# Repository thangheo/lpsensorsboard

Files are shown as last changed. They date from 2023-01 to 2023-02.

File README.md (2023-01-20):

# low power sensorsboard
một mạng cảm biến tự làm chạy bằng pin với nhiều loại cảm biến cho nhà thông minh.
PCB và sơ đồ được thiết kế bằng Kicad 6.0.
một phần của cấu hình firmare được tạo bởi STM CubeMX.

Ở phiên bản hiện tại, các cảm biến được hỗ trợ là Cường độ ánh sáng sử dụng điện trở quang (ánh sáng rất yếu, <5 Lux),
Cảm biến CO2/độ ẩm/nhiệt độ từ sensirion SCD41(từ Seeedstudio
với đầu nối Grove), cảm biến âm thanh (Micrô), cảm biến CO/NH3, cảm biến AM2320 cho độ ẩm và nhiệt độ.
Tôi chưa thử nghiệm trên phần cứng thực vì tôi chỉ thiết kế PCB và lập trình Firmware vài tuần trước.
Vi điều khiển là STM32L051 với lõi Cortex M0+, ở chế độ STANDBY, mức tiêu thụ điện năng có thể giảm xuống mức thấp nhất là vài micro amp.
Theo tính toán của tôi, thiết bị có thể chạy tới 7-8 tháng với thời gian đo 2 phút với
 Pin Lithium 18658 (1000mAh). Nếu không có cảm biến CO/NH3, nó có thể chạy tới nhiều năm mà không cần sạc lại
  pin vì cảm biến này tiêu thụ một nửa năng lượng (35mA trong tổng số 70mA).
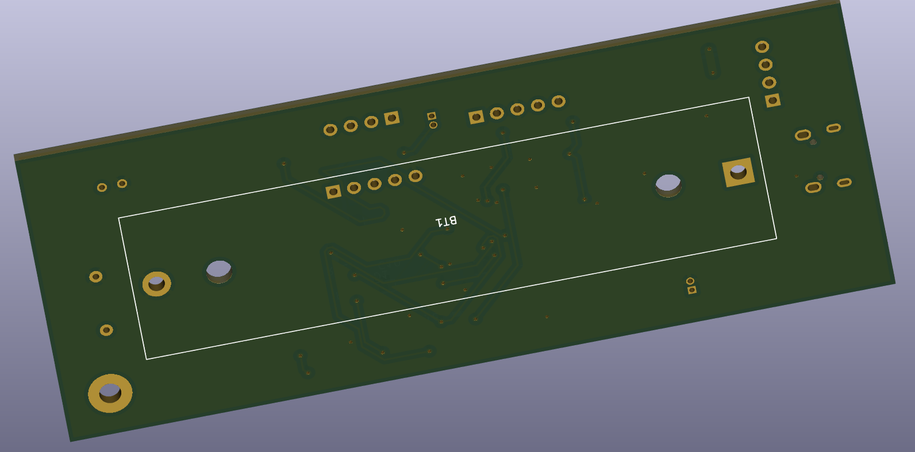
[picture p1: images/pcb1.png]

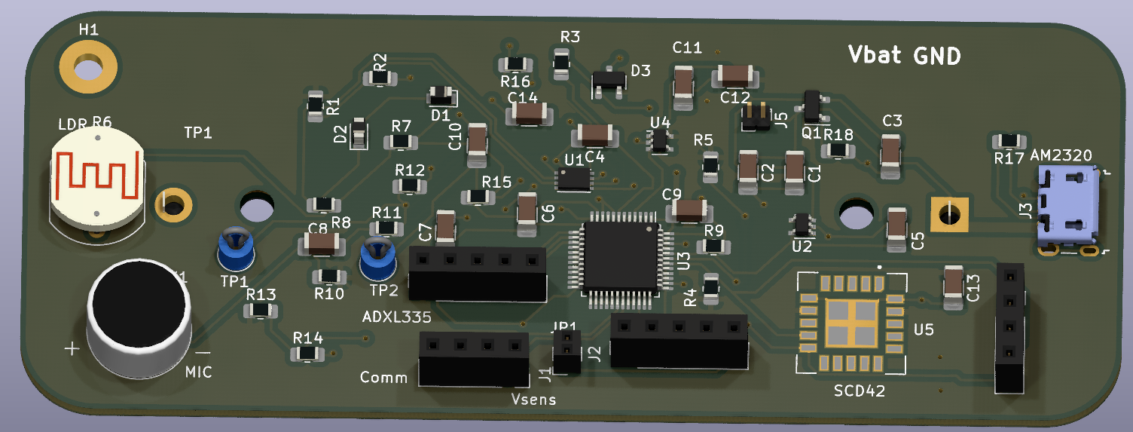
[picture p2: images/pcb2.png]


1. Cấu trúc dữ liệu gửi đi (bổ sung sau)

typedef struct {
  unsigned int temperature;
  unsigned int humidity;
  unsigned int AM2320_temperature;
  unsigned int AM2320_humidity;
  unsigned int audio;
  unsigned int light;
  unsigned int CO2;
  unsigned int NH3;
}

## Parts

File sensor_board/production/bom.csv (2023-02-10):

Designator | Footprint | Quantity | Value | LCSC Part #
BT1 | BatteryHolder_MPD_BH-18650-PC2 | 1 | Battery_Cell
C1 | 1206 | 1 | 1u
C10 | 1206 | 1 | 1u
C11 | 1206 | 1 | 1u
C12 | 1206 | 1 | 1u
C13 | 1206 | 1 | 1u
C14 | 1206 | 1 | 1n
C2 | 1206 | 1 | 4.7u
C3 | 1206 | 1 | 1u
C4 | 1206 | 1 | 0.1u
C5 | 1206 | 1 | 1u
C6 | 1206 | 1 | 0.1u
C7 | 1206 | 1 | 0.1u
C8 | 1206 | 1 | 1u
C9 | 1206 | 1 | 1u
D1, D2 | D_SOD-110 | 2 | 1N4728
D3 | SOT-23 | 1 | D_Zener_Dual_CommonAnode_KKA
H1 | MountingHole_2.7mm_M2.5_Pad | 1 | MountingHole
J1 | PinSocket_1x04_P2.54mm_Vertical | 1 | zigbee connector
J2 | PinSocket_1x05_P2.54mm_Vertical | 1 | SWD
J3 | USB_Micro-B_Wuerth_629105150521 | 1 | USB_B_Micro
J4 | PinSocket_1x04_P2.54mm_Vertical | 1 | AM2320
J5 | PinHeader_1x02_P1.27mm_Vertical | 1 | Lithium_battery_conn
J6 | PinSocket_1x05_P2.54mm_Vertical | 1 | ACC
J7 | TerminalBlock_bornier-2_P5.08mm | 1 | DBG_PWR
JP1 | PinSocket_1x02_P1.27mm_Vertical | 1 | 3.3v Jumper
MK1 | MIC_AOM-6738P-R | 1 | AOM-6738P-R
Q1 | SOT-23 | 1 | DMP3098LQ
R1 | 0805 | 1 | 100k
R10 | 0805 | 1 | 1k
R11 | 0805 | 1 | 1k
R12 | 0805 | 1 | 1k
R13 | 0805 | 1 | 22k
R14 | 0805 | 1 | 22k
R15 | 0805 | 1 | 20k
R16 | 0805 | 1 | 4.7k
R17 | 0805 | 1 | 200
R18 | 0805 | 1 | 10k
R19 | 0805 | 1 | 470
R2 | 0805 | 1 | 10k
R20 | 0805 | 1 | 470
R3 | 0805 | 1 | 10k
R4 | 0805 | 1 | 10k
R5 | 0805 | 1 | 10k
R6 | R_LDR_10x8.5mm_P7.6mm_Vertical | 1 | LDR03
R7 | 0805 | 1 | 100k
R8 | 0805 | 1 | 1k
R9 | 0805 | 1 | 10k
TP1, TP2 | TestPoint_Loop_D2.60mm_Drill1.6mm_Beaded | 2 | TestPoint
U1 | DFN-8-1EP_3x2mm_P0.5mm_EP1.75x1.45mm | 1 | MCP6002-xMC
U2, U4 | SOT-353_SC-70-5 | 2 | MIC5365-3.3YC5
U3 | LQFP-48_7x7mm_P0.5mm | 1 | STM32L051C8Tx
U5 | XDCR_SCD41-D-R2 | 1 | SDC42

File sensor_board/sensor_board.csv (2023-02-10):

Source: | /home/tng/work/nhayen/electronic/sensor/sensor_board/sensor_board.kicad_sch
Date: | Thứ ba, 07 Tháng 2 Năm 2023 21:50:40 +07
Tool: | Eeschema 6.0.11-2627ca5db0~126~ubuntu22.04.1
Generator: | /usr/share/kicad/plugins/bom_csv_grouped_by_value.py
Component Count: | 59
Individual Components:
Item | Qty | Reference(s) | Value | LibPart | Footprint | Datasheet | MANUFACTURER | MAXIMUM_PACKAGE_HEIGHT | PARTREV | SNAPEDA_PN | STANDARD
 |  | BT1 | Battery_Cell | Device:Battery_Cell | Battery:BatteryHolder_MPD_BH-18650-PC2 | ~
 |  | C1 | 1u | Device:C | Capacitor_SMD:C_1206_3216Metric_Pad1.33x1.80mm_HandSolder | ~
 |  | C2 | 4.7u | Device:C | Capacitor_SMD:C_1206_3216Metric_Pad1.33x1.80mm_HandSolder | ~
 |  | C3 | 1u | Device:C | Capacitor_SMD:C_1206_3216Metric_Pad1.33x1.80mm_HandSolder | ~
 |  | C4 | 0.1u | Device:C | Capacitor_SMD:C_1206_3216Metric_Pad1.33x1.80mm_HandSolder | ~
 |  | C5 | 1u | Device:C | Capacitor_SMD:C_1206_3216Metric_Pad1.33x1.80mm_HandSolder | ~
 |  | C6 | 0.1u | Device:C | Capacitor_SMD:C_1206_3216Metric_Pad1.33x1.80mm_HandSolder | ~
 |  | C7 | 0.1u | Device:C | Capacitor_SMD:C_1206_3216Metric_Pad1.33x1.80mm_HandSolder | ~
 |  | C8 | 1u | Device:C | Capacitor_SMD:C_1206_3216Metric_Pad1.33x1.80mm_HandSolder | ~
 |  | C9 | 1u | Device:C | Capacitor_SMD:C_1206_3216Metric_Pad1.33x1.80mm_HandSolder | ~
 |  | C10 | 1u | Device:C | Capacitor_SMD:C_1206_3216Metric_Pad1.33x1.80mm_HandSolder | ~
 |  | C11 | 1u | Device:C | Capacitor_SMD:C_1206_3216Metric_Pad1.33x1.80mm_HandSolder | ~
 |  | C12 | 1u | Device:C | Capacitor_SMD:C_1206_3216Metric_Pad1.33x1.80mm_HandSolder | ~
 |  | C13 | 1u | Device:C | Capacitor_SMD:C_1206_3216Metric_Pad1.33x1.80mm_HandSolder | ~
 |  | C14 | 1n | Device:C | Capacitor_SMD:C_1206_3216Metric_Pad1.33x1.80mm_HandSolder | ~
 |  | C15 | 0.1u | Device:C | Capacitor_SMD:C_1206_3216Metric_Pad1.33x1.80mm_HandSolder | ~
 |  | C16 | 0.1u | Device:C | Capacitor_SMD:C_1206_3216Metric_Pad1.33x1.80mm_HandSolder | ~
 |  | C17 | 0.1u | Device:C | Capacitor_SMD:C_1206_3216Metric_Pad1.33x1.80mm_HandSolder | ~
 |  | D1 | 1N4728 | Device:D_Zener | Diode_SMD:D_SOD-110 | ~
 |  | D2 | 1N4728 | Device:D_Zener | Diode_SMD:D_SOD-110 | ~
 |  | D3 | D_Zener_Dual_CommonAnode_KKA | Device:D_Zener_Dual_CommonAnode_KKA | Package_TO_SOT_SMD:SOT-23 | ~
 |  | H1 | MountingHole | Mechanical:MountingHole | MountingHole:MountingHole_2.7mm_M2.5_Pad | ~
 |  | J1 | zigbee connector | Connector:Conn_01x04_Female | Connector_PinSocket_2.54mm:PinSocket_1x04_P2.54mm_Vertical | ~
 |  | J2 | SWD | Connector:Conn_01x05_Male | Connector_PinSocket_2.54mm:PinSocket_1x05_P2.54mm_Vertical | ~
 |  | J3 | USB_B_Micro | Connector:USB_B_Micro | Connector_USB:USB_Micro-B_Wuerth_629105150521 | https://www.thegioiic.com/cong-usb-micro-b-2-0-dau-cai-5-chan-smd-v2
 |  | J4 | AM2320 | Connector:Conn_01x04_Male | Connector_PinSocket_2.54mm:PinSocket_1x04_P2.54mm_Vertical | https://www.seeedstudio.com/Grove-CO2-Temperature-Humidity-Sensor-SCD41-p-5025.html
 |  | J5 | Lithium_battery_conn | Connector:Conn_01x02_Female | Connector_PinHeader_1.27mm:PinHeader_1x02_P1.27mm_Vertical | ~
 |  | J6 | ACC | Connector:Conn_01x05_Male | Connector_PinSocket_2.54mm:PinSocket_1x05_P2.54mm_Vertical | ~
 |  | J7 | DBG_PWR | Connector:Screw_Terminal_01x02 | TerminalBlock:TerminalBlock_bornier-2_P5.08mm | https://www.thegioiic.com/kf8500-2-terminal-khoi-han-pcb-2-cuc-20a-300v-8-25mm-han-pcb
 |  | JP1 | 3.3v Jumper | Jumper:Jumper_2_Bridged | Connector_PinSocket_1.27mm:PinSocket_1x02_P1.27mm_Vertical | ~
 |  | MK1 | AOM-6738P-R | AOM-6738P-R:AOM-6738P-R | microphone:MIC_AOM-6738P-R |  | PUI Audio | 6.9 mm | B |  | IPC 7351B
 |  | Q1 | DMP3098LQ | Device:Q_PMOS_GSD | Package_TO_SOT_SMD:SOT-23 | https://www.mouser.vn/datasheet/2/115/DIOD_S_A0002960474_1-2542057.pdf
 |  | R1 | 100k | Device:R | Resistor_SMD:R_0805_2012Metric_Pad1.20x1.40mm_HandSolder | ~
 |  | R2 | 10k | Device:R | Resistor_SMD:R_0805_2012Metric_Pad1.20x1.40mm_HandSolder | ~
 |  | R3 | 10k | Device:R | Resistor_SMD:R_0805_2012Metric_Pad1.20x1.40mm_HandSolder | ~
 |  | R4 | 10k | Device:R | Resistor_SMD:R_0805_2012Metric_Pad1.20x1.40mm_HandSolder | ~
 |  | R5 | 10k | Device:R | Resistor_SMD:R_0805_2012Metric_Pad1.20x1.40mm_HandSolder | ~
 |  | R6 | LDR03 | Sensor_Optical:LDR03 | OptoDevice:R_LDR_10x8.5mm_P7.6mm_Vertical | http://www.elektronica-componenten.nl/WebRoot/StoreNL/Shops/61422969/54F1/BA0C/C664/31B9/2173/C0A8/2AB9/2AEF/LDR03IMP.pdf
 |  | R7 | 100k | Device:R | Resistor_SMD:R_0805_2012Metric_Pad1.20x1.40mm_HandSolder | ~
 |  | R8 | 1k | Device:R | Resistor_SMD:R_0805_2012Metric_Pad1.20x1.40mm_HandSolder | ~
 |  | R9 | 10k | Device:R | Resistor_SMD:R_0805_2012Metric_Pad1.20x1.40mm_HandSolder | ~
 |  | R10 | 1k | Device:R | Resistor_SMD:R_0805_2012Metric_Pad1.20x1.40mm_HandSolder | ~
 |  | R11 | 1k | Device:R | Resistor_SMD:R_0805_2012Metric_Pad1.20x1.40mm_HandSolder | ~
 |  | R12 | 1k | Device:R | Resistor_SMD:R_0805_2012Metric_Pad1.20x1.40mm_HandSolder | ~
 |  | R13 | 22k | Device:R | Resistor_SMD:R_0805_2012Metric_Pad1.20x1.40mm_HandSolder | ~
 |  | R14 | 22k | Device:R | Resistor_SMD:R_0805_2012Metric_Pad1.20x1.40mm_HandSolder | ~
 |  | R15 | 20k | Device:R | Resistor_SMD:R_0805_2012Metric_Pad1.20x1.40mm_HandSolder | ~
 |  | R16 | 4.7k | Device:R | Resistor_SMD:R_0805_2012Metric_Pad1.20x1.40mm_HandSolder | ~
 |  | R17 | 200 | Device:R | Resistor_SMD:R_0805_2012Metric_Pad1.20x1.40mm_HandSolder | ~
 |  | R18 | 10k | Device:R | Resistor_SMD:R_0805_2012Metric_Pad1.20x1.40mm_HandSolder | ~
 |  | R19 | 470 | Device:R | Resistor_SMD:R_0805_2012Metric_Pad1.20x1.40mm_HandSolder | ~
 |  | R20 | 470 | Device:R | Resistor_SMD:R_0805_2012Metric_Pad1.20x1.40mm_HandSolder | ~
 |  | TP1 | TestPoint | Connector:TestPoint | TestPoint:TestPoint_Loop_D2.60mm_Drill1.6mm_Beaded | ~
 |  | TP2 | TestPoint | Connector:TestPoint | TestPoint:TestPoint_Loop_D2.60mm_Drill1.6mm_Beaded | ~
 |  | U1 | MCP6002-xMC | Amplifier_Operational:MCP6002-xMC | Package_DFN_QFN:DFN-8-1EP_3x2mm_P0.5mm_EP1.75x1.45mm | https://www.thegioiic.com/mcp6002-i-sn-ic-opamp-general-purpose-amplifier-2-circuit-1mhz-8-soic
 |  | U2 | MIC5365-3.3YC5 | Regulator_Linear:MIC5365-3.3YC5 | Package_TO_SOT_SMD:SOT-353_SC-70-5 | http://ww1.microchip.com/downloads/en/DeviceDoc/mic5365.pdf
 |  | U3 | STM32L051C8Tx | MCU_ST_STM32L0:STM32L051C8Tx | Package_QFP:LQFP-48_7x7mm_P0.5mm | https://www.thegioiic.com/stm32l051c8t6
 |  | U4 | MIC5365-3.3YC5 | Regulator_Linear:MIC5365-3.3YC5 | Package_TO_SOT_SMD:SOT-353_SC-70-5 | http://ww1.microchip.com/downloads/en/DeviceDoc/mic5365.pdf
 |  | U5 | SDC42 | SCD41-D-R2:SCD41-D-R2 | SCD41-D-R2:XDCR_SCD41-D-R2 |  | Sensirion | 6.8mm | 1.2 | SCD41-D-R2 | Manufacturer Recommendations
Collated Components:
Item | Qty | Reference(s) | Value | LibPart | Footprint | Datasheet | MANUFACTURER | MAXIMUM_PACKAGE_HEIGHT | PARTREV | SNAPEDA_PN | STANDARD
1 | 1 | BT1 | Battery_Cell | Device:Battery_Cell | Battery:BatteryHolder_MPD_BH-18650-PC2 | ~
2 | 9 | C1, C3, C5, C8, C9, C10, C11, C12, C13 | 1u | Device:C | Capacitor_SMD:C_1206_3216Metric_Pad1.33x1.80mm_HandSolder | ~
3 | 1 | C2 | 4.7u | Device:C | Capacitor_SMD:C_1206_3216Metric_Pad1.33x1.80mm_HandSolder | ~
4 | 6 | C4, C6, C7, C15, C16, C17 | 0.1u | Device:C | Capacitor_SMD:C_1206_3216Metric_Pad1.33x1.80mm_HandSolder | ~
5 | 1 | C14 | 1n | Device:C | Capacitor_SMD:C_1206_3216Metric_Pad1.33x1.80mm_HandSolder | ~
6 | 2 | D1, D2 | 1N4728 | Device:D_Zener | Diode_SMD:D_SOD-110 | ~
7 | 1 | D3 | D_Zener_Dual_CommonAnode_KKA | Device:D_Zener_Dual_CommonAnode_KKA | Package_TO_SOT_SMD:SOT-23 | ~
8 | 1 | H1 | MountingHole | Mechanical:MountingHole | MountingHole:MountingHole_2.7mm_M2.5_Pad | ~
9 | 1 | J1 | zigbee connector | Connector:Conn_01x04_Female | Connector_PinSocket_2.54mm:PinSocket_1x04_P2.54mm_Vertical | ~
10 | 1 | J2 | SWD | Connector:Conn_01x05_Male | Connector_PinSocket_2.54mm:PinSocket_1x05_P2.54mm_Vertical | ~
11 | 1 | J3 | USB_B_Micro | Connector:USB_B_Micro | Connector_USB:USB_Micro-B_Wuerth_629105150521 | https://www.thegioiic.com/cong-usb-micro-b-2-0-dau-cai-5-chan-smd-v2
12 | 1 | J4 | AM2320 | Connector:Conn_01x04_Male | Connector_PinSocket_2.54mm:PinSocket_1x04_P2.54mm_Vertical | https://www.seeedstudio.com/Grove-CO2-Temperature-Humidity-Sensor-SCD41-p-5025.html
13 | 1 | J5 | Lithium_battery_conn | Connector:Conn_01x02_Female | Connector_PinHeader_1.27mm:PinHeader_1x02_P1.27mm_Vertical | ~
14 | 1 | J6 | ACC | Connector:Conn_01x05_Male | Connector_PinSocket_2.54mm:PinSocket_1x05_P2.54mm_Vertical | ~
15 | 1 | J7 | DBG_PWR | Connector:Screw_Terminal_01x02 | TerminalBlock:TerminalBlock_bornier-2_P5.08mm | https://www.thegioiic.com/kf8500-2-terminal-khoi-han-pcb-2-cuc-20a-300v-8-25mm-han-pcb
16 | 1 | JP1 | 3.3v Jumper | Jumper:Jumper_2_Bridged | Connector_PinSocket_1.27mm:PinSocket_1x02_P1.27mm_Vertical | ~
17 | 1 | MK1 | AOM-6738P-R | AOM-6738P-R:AOM-6738P-R | microphone:MIC_AOM-6738P-R |  | PUI Audio | 6.9 mm | B |  | IPC 7351B
18 | 1 | Q1 | DMP3098LQ | Device:Q_PMOS_GSD | Package_TO_SOT_SMD:SOT-23 | https://www.mouser.vn/datasheet/2/115/DIOD_S_A0002960474_1-2542057.pdf
19 | 2 | R1, R7 | 100k | Device:R | Resistor_SMD:R_0805_2012Metric_Pad1.20x1.40mm_HandSolder | ~
20 | 6 | R2, R3, R4, R5, R9, R18 | 10k | Device:R | Resistor_SMD:R_0805_2012Metric_Pad1.20x1.40mm_HandSolder | ~
21 | 1 | R6 | LDR03 | Sensor_Optical:LDR03 | OptoDevice:R_LDR_10x8.5mm_P7.6mm_Vertical | http://www.elektronica-componenten.nl/WebRoot/StoreNL/Shops/61422969/54F1/BA0C/C664/31B9/2173/C0A8/2AB9/2AEF/LDR03IMP.pdf
22 | 4 | R8, R10, R11, R12 | 1k | Device:R | Resistor_SMD:R_0805_2012Metric_Pad1.20x1.40mm_HandSolder | ~
23 | 2 | R13, R14 | 22k | Device:R | Resistor_SMD:R_0805_2012Metric_Pad1.20x1.40mm_HandSolder | ~
24 | 1 | R15 | 20k | Device:R | Resistor_SMD:R_0805_2012Metric_Pad1.20x1.40mm_HandSolder | ~
25 | 1 | R16 | 4.7k | Device:R | Resistor_SMD:R_0805_2012Metric_Pad1.20x1.40mm_HandSolder | ~
26 | 1 | R17 | 200 | Device:R | Resistor_SMD:R_0805_2012Metric_Pad1.20x1.40mm_HandSolder | ~
27 | 2 | R19, R20 | 470 | Device:R | Resistor_SMD:R_0805_2012Metric_Pad1.20x1.40mm_HandSolder | ~
28 | 2 | TP1, TP2 | TestPoint | Connector:TestPoint | TestPoint:TestPoint_Loop_D2.60mm_Drill1.6mm_Beaded | ~
29 | 1 | U1 | MCP6002-xMC | Amplifier_Operational:MCP6002-xMC | Package_DFN_QFN:DFN-8-1EP_3x2mm_P0.5mm_EP1.75x1.45mm | https://www.thegioiic.com/mcp6002-i-sn-ic-opamp-general-purpose-amplifier-2-circuit-1mhz-8-soic
30 | 2 | U2, U4 | MIC5365-3.3YC5 | Regulator_Linear:MIC5365-3.3YC5 | Package_TO_SOT_SMD:SOT-353_SC-70-5 | http://ww1.microchip.com/downloads/en/DeviceDoc/mic5365.pdf
31 | 1 | U3 | STM32L051C8Tx | MCU_ST_STM32L0:STM32L051C8Tx | Package_QFP:LQFP-48_7x7mm_P0.5mm | https://www.thegioiic.com/stm32l051c8t6
32 | 1 | U5 | SDC42 | SCD41-D-R2:SCD41-D-R2 | SCD41-D-R2:XDCR_SCD41-D-R2 |  | Sensirion | 6.8mm | 1.2 | SCD41-D-R2 | Manufacturer Recommendations

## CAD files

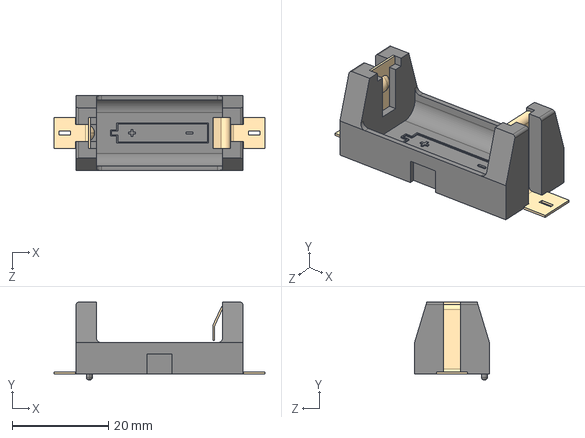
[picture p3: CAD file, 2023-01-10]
kicad_lib/1010/1010.step
43.8 x 16.1 x 15.5 mm

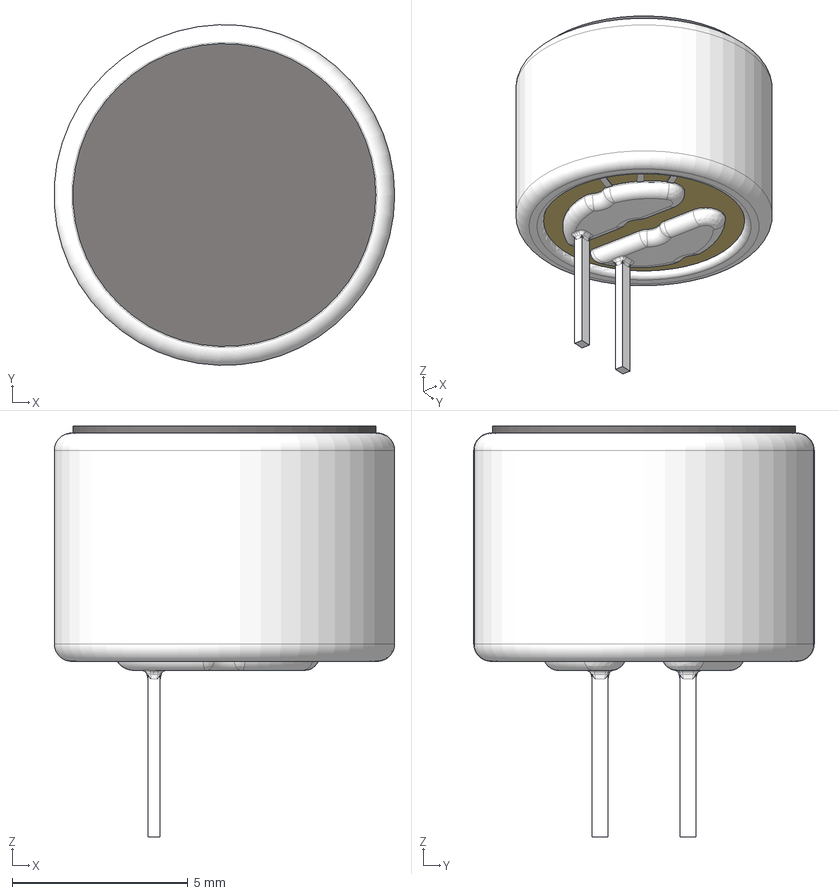
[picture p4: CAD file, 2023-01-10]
kicad_lib/AOM-6738P-R--3DModel-STEP-1.STEP
9.69 x 9.70 x 11.7 mm

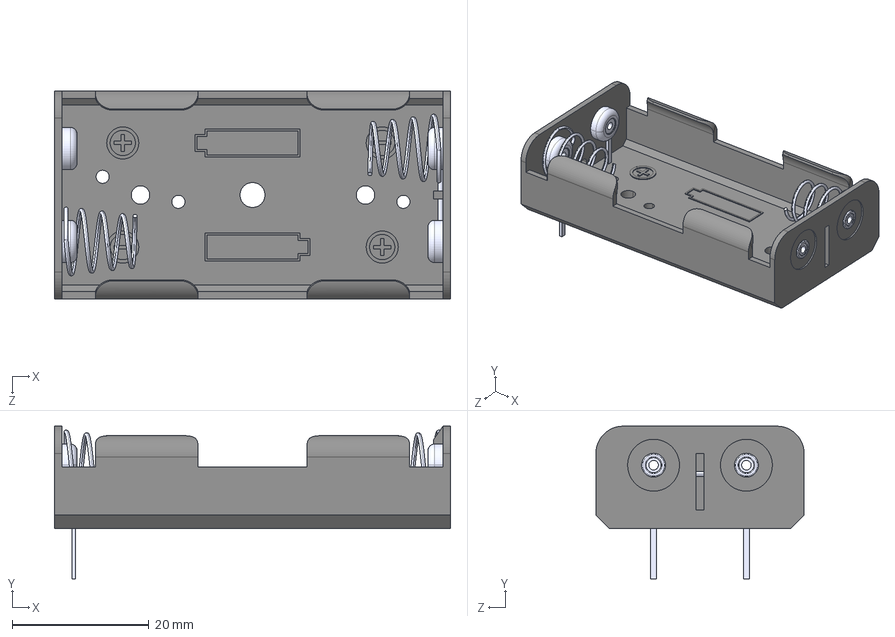
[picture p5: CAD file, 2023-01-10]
kicad_lib/BC2AAPC/BC2AAPC.step
58.0 x 22.4 x 30.5 mm

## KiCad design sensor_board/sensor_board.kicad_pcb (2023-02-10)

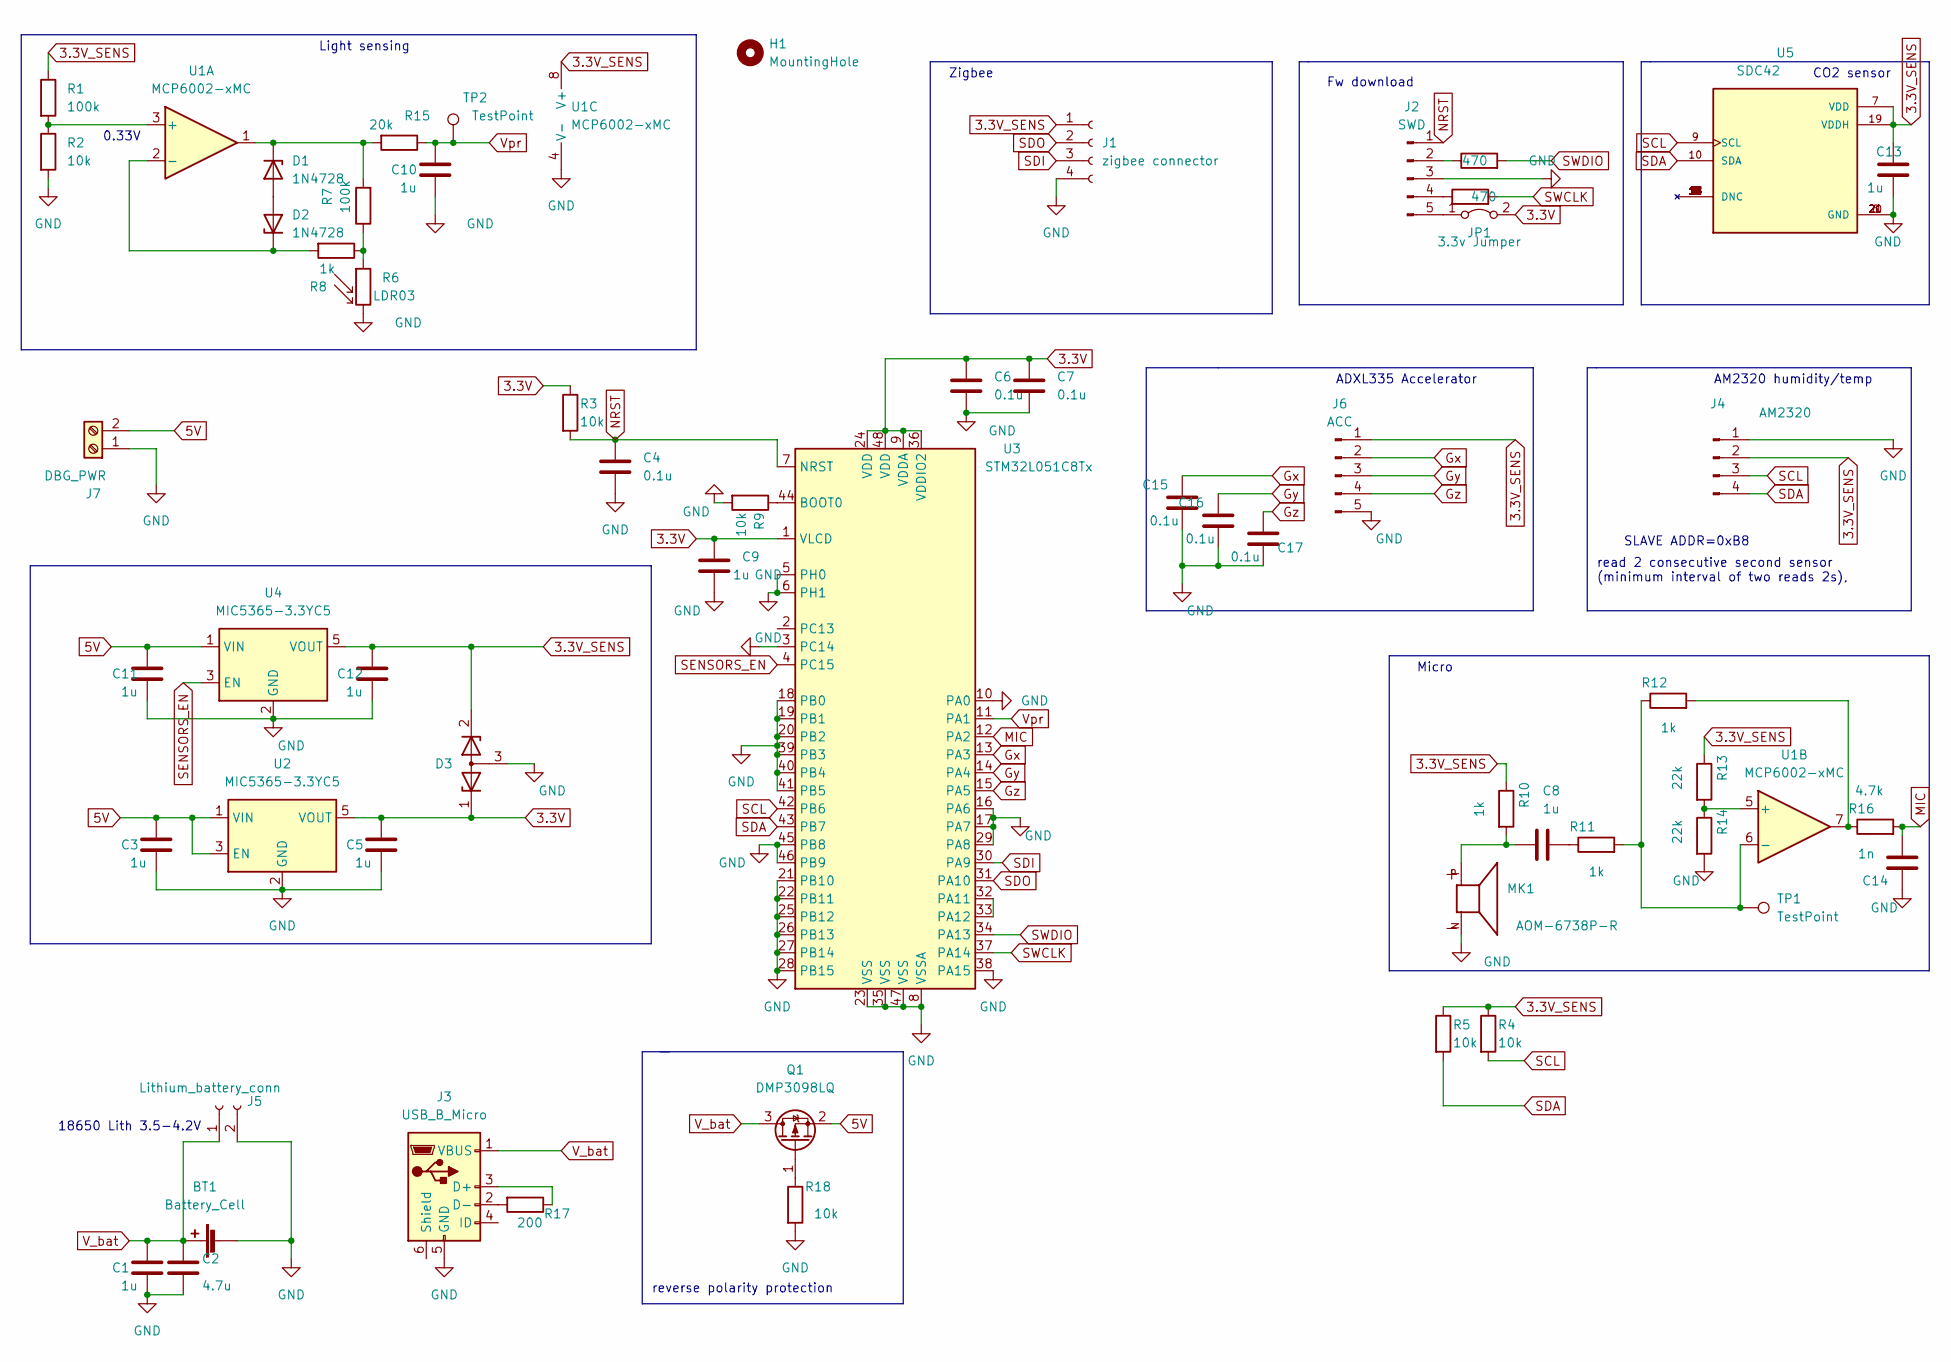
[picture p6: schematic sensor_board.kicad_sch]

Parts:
BT1: Battery_Cell; BatteryHolder_MPD_BH-18650-PC2
C1, C3, C5, C8, C9, C10, C11, C12, C13: 1u; C_1206_3216Metric_Pad1.33x1.80mm_HandSolder
C2: 4.7u; C_1206_3216Metric_Pad1.33x1.80mm_HandSolder
C4, C6, C7, C15, C16, C17: 0.1u; C_1206_3216Metric_Pad1.33x1.80mm_HandSolder
C14: 1n; C_1206_3216Metric_Pad1.33x1.80mm_HandSolder
D1, D2: 1N4728; D_SOD-110
D3: D_Zener_Dual_CommonAnode_KKA; SOT-23
H1: MountingHole; MountingHole_2.7mm_M2.5_Pad
J1: zigbee connector; PinSocket_1x04_P2.54mm_Vertical
J2: SWD; PinSocket_1x05_P2.54mm_Vertical
J3: USB_B_Micro; USB_Micro-B_Wuerth_629105150521
J4: AM2320; PinSocket_1x04_P2.54mm_Vertical
J5: Lithium_battery_conn; PinHeader_1x02_P1.27mm_Vertical
J6: ACC; PinSocket_1x05_P2.54mm_Vertical
J7: DBG_PWR; TerminalBlock_bornier-2_P5.08mm
JP1: 3.3v Jumper; PinSocket_1x02_P1.27mm_Vertical
MK1: AOM-6738P-R; MIC_AOM-6738P-R; PARTREV B
Q1: DMP3098LQ; SOT-23
R1, R7: 100k; R_0805_2012Metric_Pad1.20x1.40mm_HandSolder
R2, R3, R4, R5, R9, R18: 10k; R_0805_2012Metric_Pad1.20x1.40mm_HandSolder
R6: LDR03; R_LDR_10x8.5mm_P7.6mm_Vertical
R8, R10, R11, R12: 1k; R_0805_2012Metric_Pad1.20x1.40mm_HandSolder
R13, R14: 22k; R_0805_2012Metric_Pad1.20x1.40mm_HandSolder
R15: 20k; R_0805_2012Metric_Pad1.20x1.40mm_HandSolder
R16: 4.7k; R_0805_2012Metric_Pad1.20x1.40mm_HandSolder
R17: 200; R_0805_2012Metric_Pad1.20x1.40mm_HandSolder
R19, R20: 470; R_0805_2012Metric_Pad1.20x1.40mm_HandSolder
TP1, TP2: TestPoint; TestPoint_Loop_D2.60mm_Drill1.6mm_Beaded
U1: MCP6002-xMC; DFN-8-1EP_3x2mm_P0.5mm_EP1.75x1.45mm
U2, U4: MIC5365-3.3YC5; SOT-353_SC-70-5
U3: STM32L051C8Tx; LQFP-48_7x7mm_P0.5mm
U5: SDC42; XDCR_SCD41-D-R2; PARTREV 1.2

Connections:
3.3V: C5.1, C6.1, C7.1, C9.1, D3.1 (K), JP1.2 (B), R3.1, U2.5 (VOUT), U3.1 (VLCD), U3.9 (VDDA), U3.24 (VDD), U3.36 (VDDIO2), U3.48 (VDD)
3.3V_SENS: C12.1, C13.1, D3.2 (K), J1.1, J4.2, J6.1, R1.1, R4.1, R5.1, R10.1, R13.1, U1.8 (V+), U4.5 (VOUT), U5.7 (VDD), U5.19 (VDDH)
5V: C3.1, C11.1, J7.2, Q1.2 (S), U2.1 (VIN), U2.3 (EN), U4.1 (VIN)
GND: BT1.2 (-), C1.2, C2.2, C3.2, C4.2, C5.2, C6.2, C7.2, C9.2, C10.2, C11.2, C12.2, C13.2, C14.1, C15.1, C16.1, C17.1, D3.3 (A), J1.4, J2.3, J3.5 (GND), J4.1, J5.2, J6.5, J7.1, MK1.N, R2.2, R6.2, R9.2, R14.2, R18.2, U1.4 (V-), U1.9 (V-), U2.2 (GND), U3.3 (PC14), U3.5 (PH0), U3.6 (PH1), U3.8 (VSSA), U3.10 (PA0), U3.16 (PA6), U3.17 (PA7), U3.18 (PB0), U3.19 (PB1), U3.20 (PB2), U3.21 (PB10), U3.22 (PB11), U3.23 (VSS), U3.25 (PB12), U3.26 (PB13), U3.27 (PB14), U3.28 (PB15), U3.29 (PA8), U3.35 (VSS), U3.38 (PA15), U3.39 (PB3), U3.40 (PB4), U3.41 (PB5), U3.45 (PB8), U3.46 (PB9), U3.47 (VSS), U4.2 (GND), U5.6 (GND), U5.20 (GND), U5.21 (GND)
Gx: C15.2, J6.2, U3.13 (PA3)
Gy: C16.2, J6.3, U3.14 (PA4)
Gz: C17.2, J6.4, U3.15 (PA5)
MIC: C14.2, R16.2, U3.12 (PA2)
NRST: C4.1, J2.1, R3.2, U3.7 (NRST)
unnamed: C8.1, MK1.P, R10.2
unnamed: C8.2, R11.1
unnamed: D1.1 (K), R7.2, R15.2, U1.1
unnamed: D1.2 (A), D2.2 (A)
unnamed: D2.1 (K), R8.2, U1.2 (-)
unnamed: J2.2, R20.1
unnamed: J2.4, R19.1
unnamed: J2.5, JP1.1 (A)
unnamed: J3.2 (D-), R17.2
unnamed: J3.3 (D+), R17.1
unnamed: Q1.1 (G), R18.1
unnamed: R1.2, R2.1, U1.3 (+)
unnamed: R6.1, R7.1, R8.1
unnamed: R9.1, U3.44 (BOOT0)
unnamed: R11.2, R12.1, TP1.1, U1.6 (-)
unnamed: R12.2, R16.1, U1.7
unnamed: R13.2, R14.1, U1.5 (+)
unnamed: U3.32 (PA11), U3.33 (PA12)
SCL: J4.3, R4.2, U3.42 (PB6), U5.9 (SCL)
SDA: J4.4, R5.2, U3.43 (PB7), U5.10 (SDA)
SDI: J1.3, U3.30 (PA9)
SDO: J1.2, U3.31 (PA10)
SENSORS_EN: U3.4 (PC15), U4.3 (EN)
SWCLK: R19.2, U3.37 (PA14)
SWDIO: R20.2, U3.34 (PA13)
V_bat: BT1.1 (+), C1.1, C2.1, J3.1 (VBUS), J5.1, Q1.3 (D)
Vpr: C10.1, R15.1, TP2.1, U3.11 (PA1)

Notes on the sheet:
read 2 consecutive second sensor (minimum interval of two reads 2s),
Zigbee
18650 Lith 3.5-4.2V
0.33V
ADXL335 Accelerator
CO2 sensor
Light sensing
reverse polarity protection
Micro
Fw download
AM2320 humidity/temp
SLAVE ADDR=0xB8

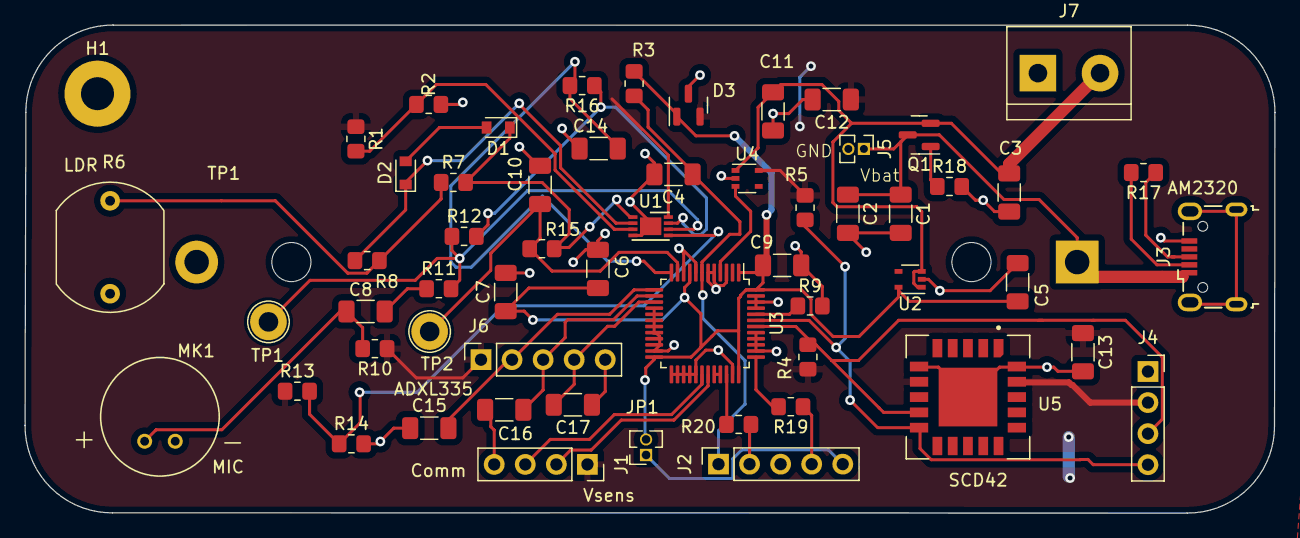
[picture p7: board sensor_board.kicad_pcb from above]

Board: 2 copper layers, 102.2 x 39.9 mm, 59 parts (1 on the bottom side), 36 nets.

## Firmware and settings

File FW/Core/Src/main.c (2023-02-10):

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
/* Includes ------------------------------------------------------------------*/
#include "main.h"
#include "cmsis_os.h"
#include "app.h"
#include "i2c.h"
#include "event_groups.h"
#include "semphr.h" 

ADC_HandleTypeDef hadc;

I2C_HandleTypeDef hi2c1;

LPTIM_HandleTypeDef hlptim1;

RTC_HandleTypeDef hrtc;

UART_HandleTypeDef huart1;

WWDG_HandleTypeDef hwwdg;
EventGroupHandle_t xSensorsEventGroup;
SemaphoreHandle_t ADC1_Mutex;
SemaphoreHandle_t I2C1_Mutex;
/* Definitions for defaultTask */
osThreadId_t defaultTaskHandle;
const osThreadAttr_t defaultTask_attributes = {
  .name = "defaultTask",
  .stack_size = configMINIMAL_STACK_SIZE * 4,
  .priority = (osPriority_t) osPriorityNormal,
};
void SystemClock_Config(void);
static void MX_GPIO_Init(void);
static void MX_ADC_Init(void);
static void MX_I2C1_Init(void);
static void MX_LPTIM1_Init(void);
static void MX_USART1_UART_Init(void);
static void MX_RTC_Init(void);
static void MX_WWDG_Init(void);
void StartDefaultTask(void *argument);
void SystemPower_Config(void);
/**
  * @brief  The application entry point.
  * @retval int
  */
int main(void)
{
    HAL_Init();
    /* Configure the system clock */
    SystemClock_Config();
    /* Initialize all configured peripherals */
    MX_GPIO_Init();
    MX_ADC_Init();
    // MX_I2C1_Init();
    i2c_init();

    MX_LPTIM1_Init();
    MX_USART1_UART_Init();
    MX_RTC_Init();
    // MX_WWDG_Init();
    /* USER CODE BEGIN 2 */
    /* Configure the system Power */
    SystemPower_Config();
    
    /* Check and handle if the system was resumed from Standby mode */ 
    if(__HAL_PWR_GET_FLAG(PWR_FLAG_SB) != RESET)
    {
      /* Clear Standby flag */
      __HAL_PWR_CLEAR_FLAG(PWR_FLAG_SB);
    }
    /*The Following Wakeup sequence is highly recommended prior to each Standby mode entry
      mainly  when using more than one wakeup source this is to not miss any wakeup event.
        - Disable all used wakeup sources,
        - Clear all related wakeup flags, 
        - Re-enable all used wakeup sources,
        - Enter the Standby mode.
      */
      /*Disable all used wakeup sources: Pin1(PA.0)*/
    HAL_PWR_DisableWakeUpPin(PWR_WAKEUP_PIN2);
    
    /*Clear all related wakeup flags*/
    __HAL_PWR_CLEAR_FLAG(PWR_FLAG_WU);
    
    /*Re-enable all used wakeup sources: Pin2(PC.13)*/
    HAL_PWR_EnableWakeUpPin(PWR_WAKEUP_PIN2);
    //setup RTC for wakeup interrupt
    MX_RTC_Init();

    //turn on sensors power supply
    HAL_GPIO_WritePin(GPIOC, GPIO_PIN_15, GPIO_PIN_SET);
    /* USER CODE END 2 */

    /* Init scheduler */
    osKernelInitialize();

      /* Attempt to create the event group. */
    xSensorsEventGroup = xEventGroupCreate();
    /* create mutexs*/
    ADC1_Mutex = xSemaphoreCreateMutex();
    I2C1_Mutex = xSemaphoreCreateMutex();


    /* Create the thread(s) */

    /* creation of defaultTask */
    defaultTaskHandle = osThreadNew(StartDefaultTask, NULL, &defaultTask_attributes);
    sensor_data_fusion_t m_sensor_data_fusion;
    /* SET SENSIR ID HERE*/
    /* 0x0-0x99 for inside sensor -0x100-0x200 for outside*/
    
    #warning "set sensor ID before flash"
    // #define INSIDE_SENSOR 
    // #define OUTSIDE_SENSOR 
    #ifdef OUTSIDE_SENSOR 
      m_sensor_data_fusion.sensorID = 0x100;
      #warning " OUTSIDE_SENSOR. ID 0x100"

      xTaskCreate(read_accel_sensor_task,"acceleration",configMINIMAL_STACK_SIZE,&m_sensor_data_fusion,6,NULL);
      xTaskCreate(&read_light_sensor_task,"light_sensor",configMINIMAL_STACK_SIZE,&m_sensor_data_fusion,2,NULL);
      xTaskCreate(read_AM2320_hu_temp_data,"AM2320",configMINIMAL_STACK_SIZE,&m_sensor_data_fusion,9,NULL);
      // xTaskCreate(read_audio_data_task,"mic",configMINIMAL_STACK_SIZE,&m_sensor_data_fusion,3,NULL);
      // xTaskCreate(read_sensirion_data_task,"scd4x",configMINIMAL_STACK_SIZE,&m_sensor_data_fusion,2,NULL);
      // xTaskCreate(read_NH3_data_task,"NH3",configMINIMAL_STACK_SIZE,&m_sensor_data_fusion,4,NULL);
      xTaskCreate(power_saving_task,"power_saving",configMINIMAL_STACK_SIZE,&m_sensor_data_fusion,8,NULL);
      xTaskCreate(tx_to_controller_task,"data_transfer",configMINIMAL_STACK_SIZE,&m_sensor_data_fusion,15,NULL);
    #else 
      m_sensor_data_fusion.sensorID = 0x1;
      #warning " INSIDE_SENSOR. ID 0x1"

      xTaskCreate(&read_light_sensor_task,"light_sensor",configMINIMAL_STACK_SIZE,&m_sensor_data_fusion,2,NULL);
      xTaskCreate(read_AM2320_hu_temp_data,"AM2320",configMINIMAL_STACK_SIZE,&m_sensor_data_fusion,9,NULL);
      xTaskCreate(read_audio_data_task,"mic",configMINIMAL_STACK_SIZE,&m_sensor_data_fusion,3,NULL);
      xTaskCreate(read_sensirion_data_task,"scd4x",configMINIMAL_STACK_SIZE,&m_sensor_data_fusion,2,NULL);
      xTaskCreate(read_NH3_data_task,"NH3",configMINIMAL_STACK_SIZE,&m_sensor_data_fusion,4,NULL);
      xTaskCreate(power_saving_task,"power_saving",configMINIMAL_STACK_SIZE,&m_sensor_data_fusion,8,NULL);
      xTaskCreate(tx_to_controller_task,"data_transfer",configMINIMAL_STACK_SIZE,&m_sensor_data_fusion,15,NULL);
    #endif
      /* USER CODE BEGIN 3 */
    while (1)
    {
      //should never come here bc wake up is like a RESET
      // https://controllerstech.com/low-power-modes-in-stm32/
    }
    /* USER CODE END RTOS_THREADS */

    /* USER CODE BEGIN RTOS_EVENTS */
    /* add events, ... */
    /* USER CODE END RTOS_EVENTS */

    /* Start scheduler */
    osKernelStart();

    /* We should never get here as control is now taken by the scheduler */
    /* Infinite loop */
    /* USER CODE BEGIN WHILE */
    while (1)
    {
      /* USER CODE END WHILE */

      /* USER CODE BEGIN 3 */
    }
    /* USER CODE END 3 */
}
void SystemPower_Config(void)
{
  /* Enable Ultra low power mode */
  HAL_PWREx_EnableUltraLowPower();
  
  /* Enable the fast wake up from Ultra low power mode */
  HAL_PWREx_EnableFastWakeUp();
}
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
/* USER CODE BEGIN Header_StartDefaultTask */
/**
  * @brief  Function implementing the defaultTask thread.
  * @param  argument: Not used
  * @retval None
  */
/* USER CODE END Header_StartDefaultTask */
void StartDefaultTask(void *argument)
{
  /* USER CODE BEGIN 5 */
  /* Infinite loop */
  for(;;)
  {
    osDelay(1);
  }
  /* USER CODE END 5 */
}

/**
  * @brief  Period elapsed callback in non blocking mode
  * @note   This function is called  when TIM6 interrupt took place, inside
  * HAL_TIM_IRQHandler(). It makes a direct call to HAL_IncTick() to increment
  * a global variable "uwTick" used as application time base.
  * @param  htim : TIM handle
  * @retval None
  */
void HAL_TIM_PeriodElapsedCallback(TIM_HandleTypeDef *htim)
{
  if (htim->Instance == TIM6) {
    HAL_IncTick();
  }
}

/**
  * @brief  This function is executed in case of error occurrence.
  * @retval None
  */
void Error_Handler(void)
{
  /* USER CODE BEGIN Error_Handler_Debug */
  /* User can add his own implementation to report the HAL error return state */
  __disable_irq();
  while (1)
  {
  }
  /* USER CODE END Error_Handler_Debug */
}

#ifdef  USE_FULL_ASSERT
/**
  * @brief  Reports the name of the source file and the source line number
  *         where the assert_param error has occurred.
  * @param  file: pointer to the source file name
  * @param  line: assert_param error line source number
  * @retval None
  */
void assert_failed(uint8_t *file, uint32_t line)
{
  /* USER CODE BEGIN 6 */
  /* User can add his own implementation to report the file name and line number,
     ex: printf("Wrong parameters value: file %s on line %d\r\n", file, line) */
  /* USER CODE END 6 */
}
#endif /* USE_FULL_ASSERT */

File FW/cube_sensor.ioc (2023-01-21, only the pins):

Mcu.UserName=STM32L051C8Tx
PA1.Signal=ADC_IN1
PA10.Signal=USART1_RX
PA13.Signal=SYS_SWDIO
PA14.Signal=SYS_SWCLK
PA2.Signal=ADC_IN2
PA3.Signal=ADC_IN3
PA4.Signal=ADC_IN4
PA5.Signal=ADC_IN5
PA9.Signal=USART1_TX
PB6.Signal=I2C1_SCL
PB7.Signal=I2C1_SDA
PC13.Signal=RTC_OUT_ALARM
PC15-OSC32_OUT.Signal=GPIO_Output

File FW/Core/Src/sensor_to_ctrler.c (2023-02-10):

#include <stdio.h>
#include "stm32l0xx_hal.h"
#include "app.h"
extern UART_HandleTypeDef huart1;
extern __IO ITStatus UartReady = RESET;

void HAL_UART_TxCpltCallback(UART_HandleTypeDef *UartHandle)
{
  /* Set transmission flag: trasfer complete*/
  UartReady = SET;
}

void HAL_UART_RxCpltCallback(UART_HandleTypeDef *UartHandle)
{
  /* Set transmission flag: trasfer complete*/
  UartReady = SET;
}
void tx_to_controller(void* data)
{
    /*##-2- Start the transmission process #####################################*/  
    /* While the UART in reception process, user can transmit data through 
        "aTxBuffer" buffer */
    if(HAL_UART_Transmit_IT(&huart1, (uint8_t*)data, sizeof(sensor_data_fusion_t))!= HAL_OK)
    {
        Error_Handler();
    }
    
    /*##-3- Wait for the end of the transfer ###################################*/   
    while (UartReady != SET)
    {
    }
    /* Reset transmission flag */
    UartReady = RESET;

}
void rx_from_controller(void* data){

    /* Reset transmission flag */
    UartReady = RESET;
    
    /*##-4- Put UART peripheral in reception process ###########################*/  
    if(HAL_UART_Receive_IT(&huart1, (uint8_t *)data, sizeof(sensor_data_fusion_t)) != HAL_OK)
    {
        Error_Handler();
    }
    while (UartReady != SET)
    {
    }
    /* Reset transmission flag */
    UartReady = RESET;

}
 

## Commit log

2023-01-10 ignore kicad backup files
2023-01-11 replace 2 cells AA with single cell 18650 battery holder
    [sensor_board.kicad_pcb, sensor_board.kicad_sch]
2023-01-16 modified: sensor_board/sensor_board.kicad_pcb modified: sensor_board/sensor_board.kicad_sch Fix SDI pins wiring error
    [sensor_board.kicad_pcb, sensor_board.kicad_sch]
2023-01-17 1. modify schematic, replace mosfet which control sensors power with LDO IC 2. add accelerator sensor to measure wind speed 3. ..
    [sensor_board.kicad_pcb, sensor_board.kicad_sch]
2023-01-20 1. use sensorion scd42 for lower power 2. add usb micro B for testing or using with backup battery later 3. add signal RC filter
    [sensor_board.kicad_pcb, sensor_board.kicad_sch]
2023-01-20 add image
    [sensor_board.kicad_pcb]
2023-01-21 1.support FreeRTOS instead of round Robin task scheduling and remove unuse file 2. Fix scd42 task which (maybe) was wrong in implementation inherrited from Sensirion demo app
    [app.c, cube_sensor.ioc, main.c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]
2023-01-22 add reverse polarity protection mosfet and diode
    [sensor_board.csv, sensor_board.kicad_pcb, sensor_board.kicad_sch]
2023-01-23 add sensor ID
2023-01-23 1. add acceleration sensor and fix warning
    [app.c, main.c, sensirion_i2c_hal.c]
2023-01-26 add testpoints
    [sensor_board.kicad_pcb, sensor_board.kicad_sch]
2023-02-10 add cap to ..
    [bom.csv, designators.csv, positions.csv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]

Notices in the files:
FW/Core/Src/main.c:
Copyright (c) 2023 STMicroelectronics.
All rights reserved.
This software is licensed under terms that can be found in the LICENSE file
